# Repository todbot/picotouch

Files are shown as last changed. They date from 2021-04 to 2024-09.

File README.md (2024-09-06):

# picotouch

Tiny capsense touch USB MIDI keyboard from a Raspberry Pi Pico
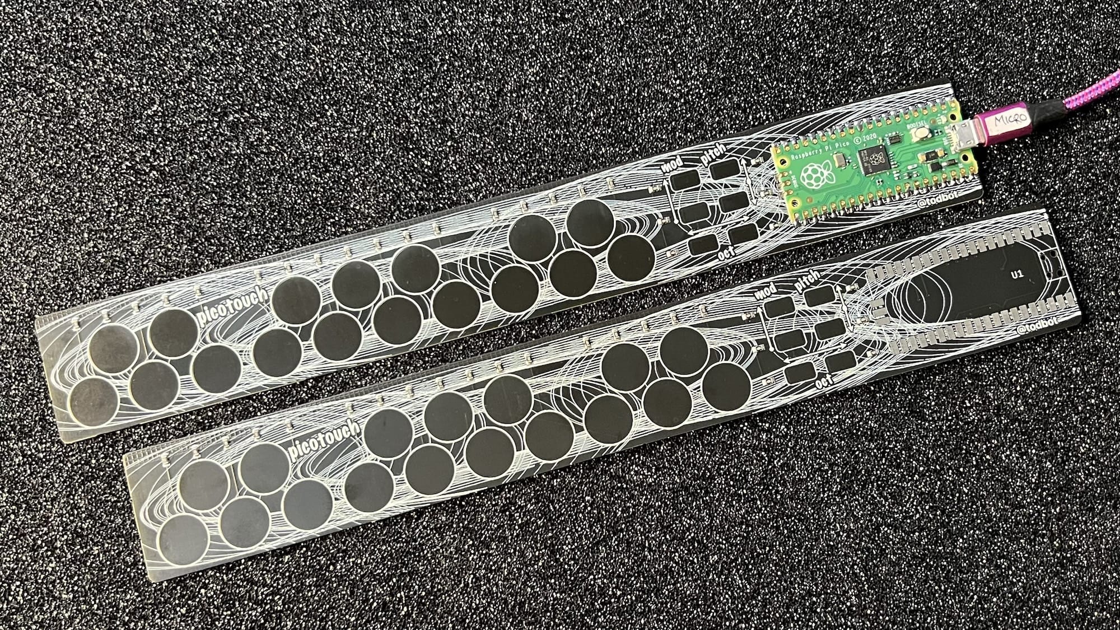
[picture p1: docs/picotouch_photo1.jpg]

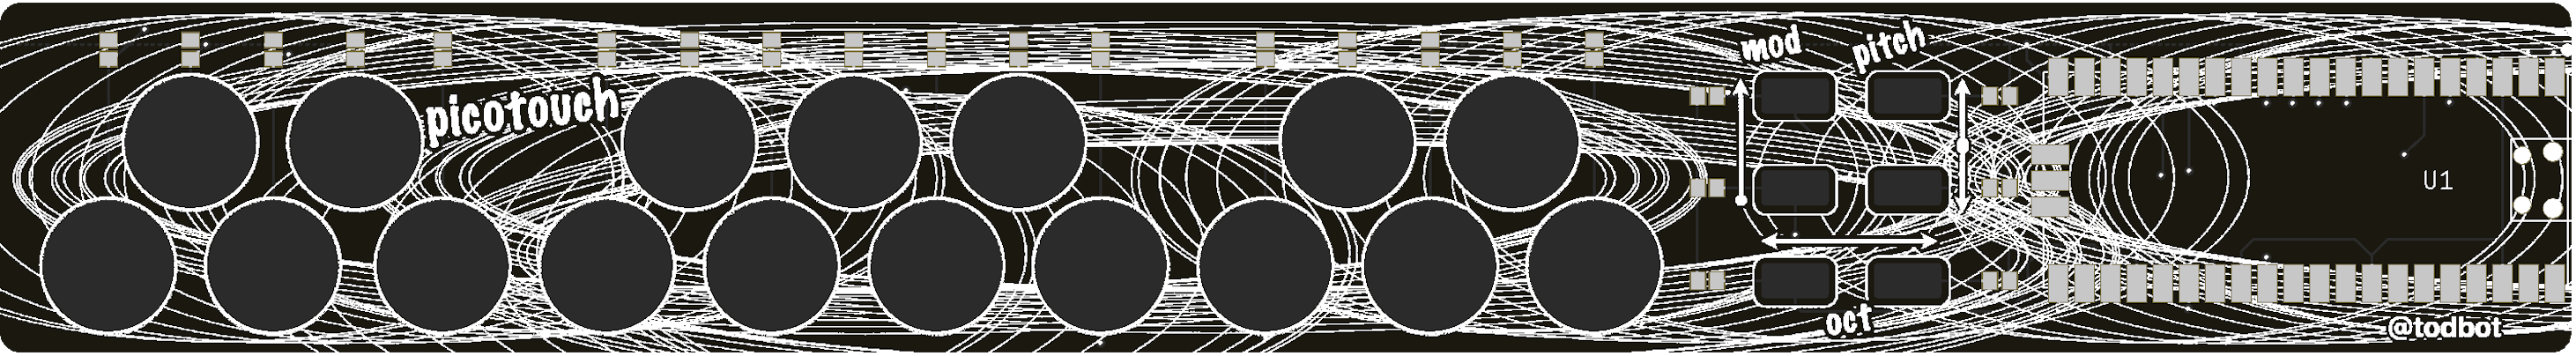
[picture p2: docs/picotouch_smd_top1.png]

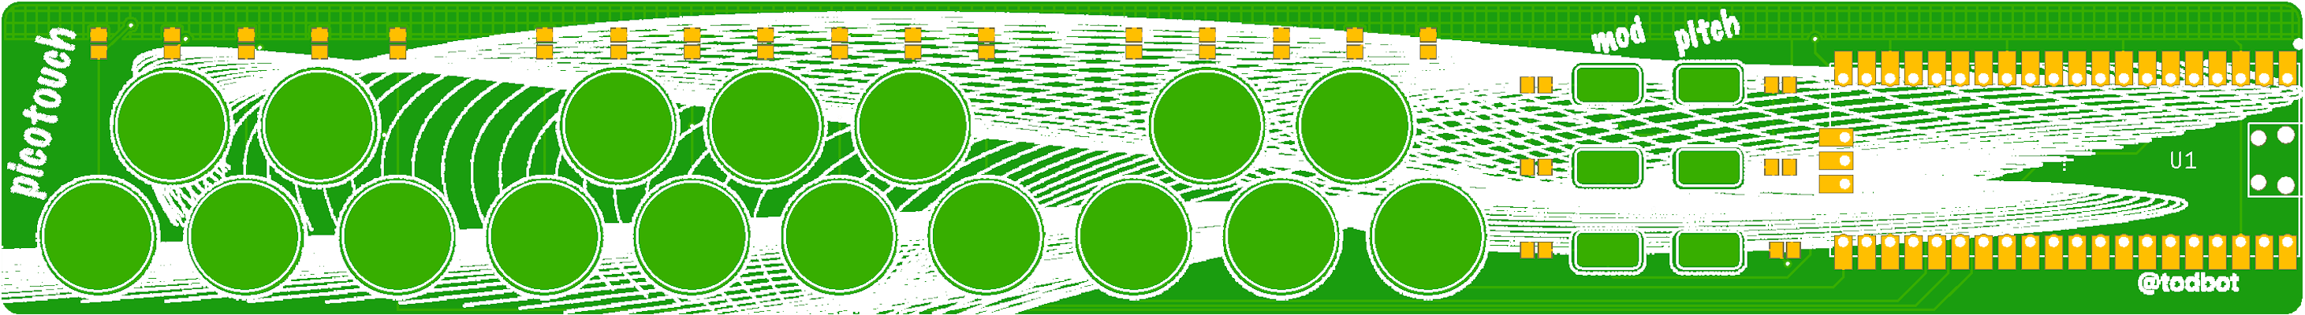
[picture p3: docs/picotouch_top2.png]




If you're looking for the synthesizer version,
that's at [github.com/todbot/picotouch_synth](https://github.com/todbot/picotouch_synth)

## Demos

https://user-images.githubusercontent.com/274093/216477797-90a1e4ca-b68f-4eb2-be46-de1d6d81551e.mp4

Also see videos in this Twitter thread : https://twitter.com/todbot/status/1382469033061093377

And check out [picotouch videos on my Youtube channel](https://www.youtube.com/@todbot/search?query=picotouch)

## Materials needed

If you [buy a black 'picotouch SMD' board from my Tindie store](https://www.tindie.com/products/todbot/picotouch-capsense-midi-keyboard-for-raspi-pico/), the <b>resistors are soldered</b> for you, so you only need to
[solder the Pico](https://www.youtube.com/watch?v=dW9LiOq3Dso).

If you're building one by hand, you will need:
- 1 - picotouch PCB ([order from OSHpark](https://oshpark.com/shared_projects/5MnI1jPf))
- 1 - Raspberry Pi Pico  **(NOTE: Not the Pico2, since its RP2350 chip has a hardware error)**
- 23 - 1M ohm 0805 SMD resistors  ([Digikey cart with this & Pico](https://www.digikey.com/short/w381rn4w))

## How to solder the Pico

It's not too bad!  A pretty easy first-time SMD soldering project.  Here's
[how to solder the Pico down](https://www.youtube.com/watch?v=dW9LiOq3Dso).
The technique is: line up the Pico solder one corner, solder the other, then finish all the rest.
In the video you see I don't get it aligned perfectly straight (hard to see around the camera), but it still works great!  ([Youtube version of the below video](https://www.youtube.com/watch?v=dW9LiOq3Dso))

https://user-images.githubusercontent.com/274093/217670870-b04d55ed-e37d-4be2-bea7-4985d2b3f8c4.mp4

## Firmware Installation

* Install CircuitPython
  - Hold down BOOT button while plugging in Pico to get RPI-RP2 drive
  - Download CircuitPython UF2 from https://circuitpython.org/board/raspberry_pi_pico/
  - Drag UF2 to RPI-RP2 drive. CircuitPython is now installed!

* Install CircuitPython libraries onto Pico
  - If you have Python on your computer you can do:
    ```
    pip3 install circup
    circup install adafruit_midi adafruit_debouncer adafruit_ticks
    ```
  - Otherwise, download the CircuitPython Libraries Bundle at https://circuitpython.org/libraries
    and copy over the `adafruit_midi`, `adafruit_debouncer`, & `adafruit_ticks` libraries
    to the `CIRCUITPY/lib` folder on the Pico.

* Install picotouch `code.py`
  - Via commandline:
    ```
    cp picotouch/circuitpython/picotouch/code.py /Volumes/CIRCUITPY/code.py
    ```
  - Or you can drag-n-drop using your computer's GUI
  - Note: this will delete the previous `code.py` on your Pico.
      Normally this is fine, but if it's not, be sure to save it if you want to keep it!

## Going further

There's other things you can do with the picotouch board.

- Use it as a MIDI slider bank

    Install
   [`picotouch_midislider/code.py`](https://github.com/todbot/picotouch/blob/main/circuitpython/picotouch_midislider/code.py) instead of the regular picotouch code.py.

   - youtube demo: [midislider demo video](https://youtu.be/1Psw3PLqYS8)

- Use it as a HID keyboard macropad

   - example code: [`picotouch_macropad/code.py`](https://github.com/todbot/picotouch/blob/main/circuitpython/picotouch_macropad/code.py)

   It's early days, but it's a start at that idea

## Press

- https://www.hackster.io/news/tod-kurt-s-ultra-slim-picotouch-is-a-button-free-23-key-raspberry-pi-pico-powered-midi-keyboard-700a3ce2227b (26 Feb 2023)
- https://www.raspberrypi.com/news/picotouch-synthesiser-magpimonday/ (22 Nov 2023)

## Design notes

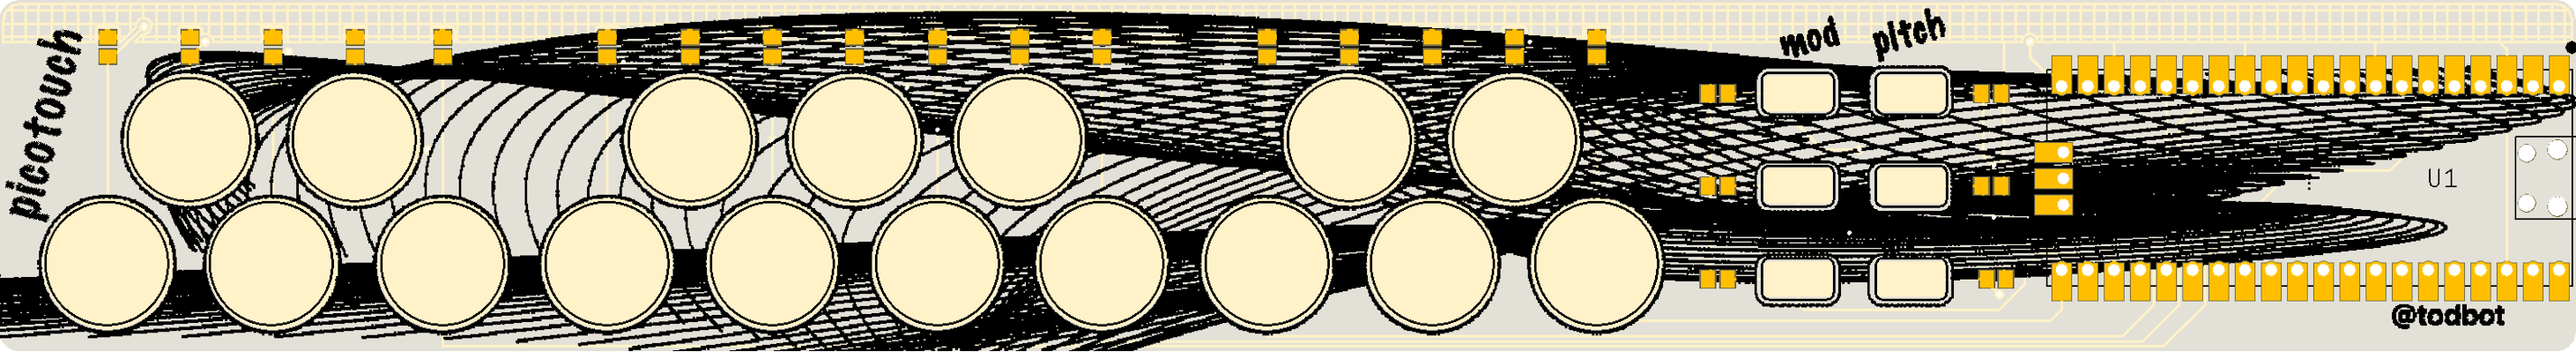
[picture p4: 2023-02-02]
docs/picotouch_top1.png

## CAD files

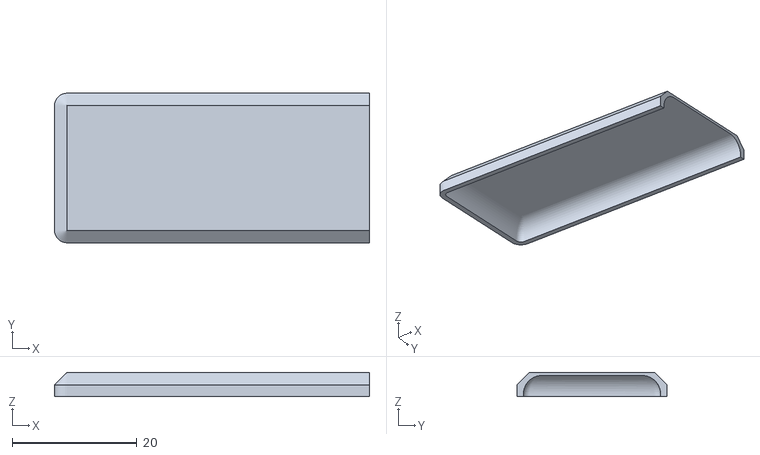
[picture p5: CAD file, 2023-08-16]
enclosure/picotouch_slidercase_picocap.stl
50.5 x 24.0 x 3.90

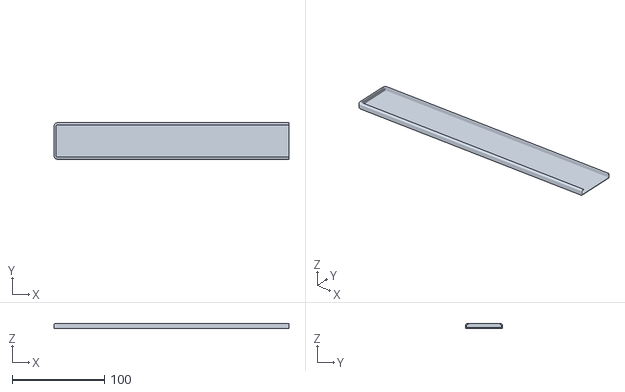
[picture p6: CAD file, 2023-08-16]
enclosure/picotouch_slidercase_bottom.stl
255.0 x 39.8 x 5.30

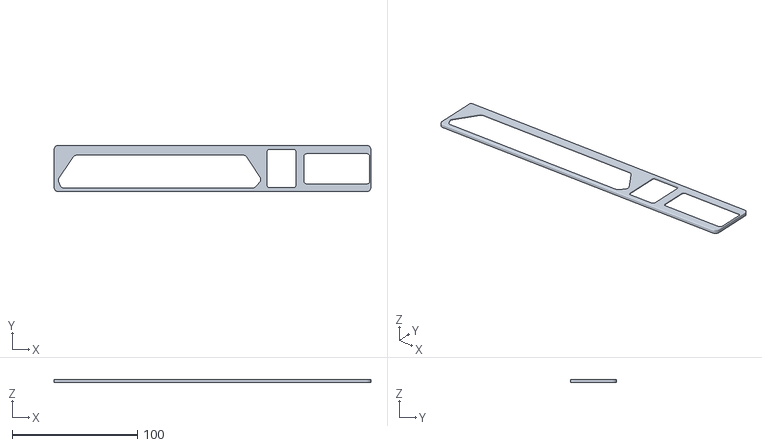
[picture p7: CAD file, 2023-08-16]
enclosure/picotouch_slidercase_top.stl
253.0 x 37.0 x 2.70

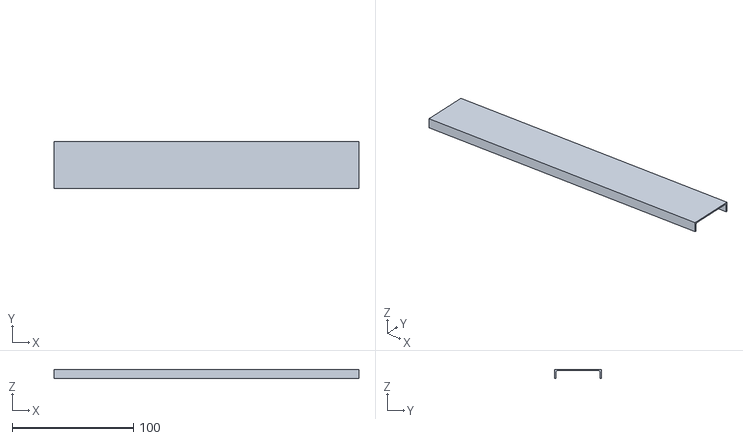
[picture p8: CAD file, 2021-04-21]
enclosure/picotouch_enclosure_top.stl
251.4 x 38.6 x 7.77

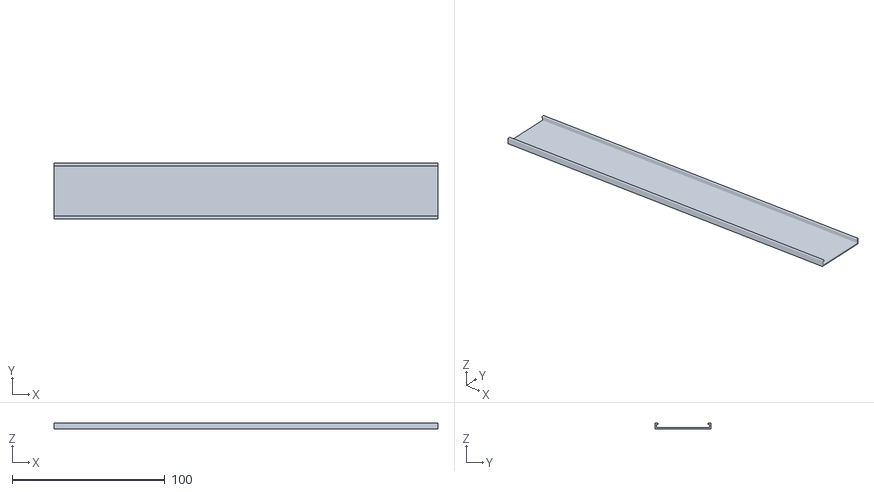
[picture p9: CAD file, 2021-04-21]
enclosure/picotouch_enclosure.stl
251.4 x 36.4 x 3.97

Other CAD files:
enclosure/picotouch_enclosure.f3z
enclosure/picotouch_slidercase v27.f3z

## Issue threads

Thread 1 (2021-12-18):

How the basic reading of individual electrode works

Sciss, 2021-12-18:
Hi there. I'm trying to understand how I could use your project as a starting point for getting capacitive proximity sensing done on a Pi Pico. If I want to bypass the PCB, what would be the minimum setup to connect a single electrode? I am looking at the [touchio API](https://circuitpython.readthedocs.io/en/latest/shared-bindings/touchio/index.html), but I don't understand how this works with a single pin. I suppose this one GPIO pin that gets toggled between output (temporary switching from low to high) and input (then reading, "counting" the delay till it returns to low)? What does your circuit do exactly; it connects one GPIO pin to one electrode, and in parallel with 1 MOhms to GND or something like that? Thanks!

todbot, 2021-12-18:
Hi,
For each `touchio` capacitive touch sensor input, all you need is one 1M ohm to ground. So it's not really a circuit exactly, just some wiring with a resistor.  There's a bit more detail about CircuitPython cap touch here: https://learn.adafruit.com/circuitpython-essentials/circuitpython-cap-touch

This video post on Twitter shows the same circuit as `pictouch` but implemented on a solderless breadboard with just a bunch of resistors, one per input.

To do a single input, it would look something like:
```py
import time
import board
import touchio

# put 1M resistor from GPO to ground, then touch GP0 to trigger
touch = touchio.TouchIn( board.GP0 )

while True:
    if touch.value:
        print("Touched!")
    time.sleep(0.05)
```

To do proximity sensing (as opposed to touch sensing) with capacitive touch, just use more metal connected to your touch input (`board.GP0` in the above example). This "more metal" could be a longer wire, wrapped into a coil, a metal plate, etc.  Note that proximity sensing is generally very finicky as it will vary based on person, ambient humidity, battery voltage, and other environmental factors.

But here's an example of doing proximity capacitive sensing using CircuitPython:
https://github.com/todbot/qtpy-tricks#use-capsense-as-proximity-detector-to-make-spooopy-ghost

Sciss, 2021-12-19:
Thanks a lot for taking the time, I'll try this out. It's all a bit of a mystery, there is just a confusing amount of alternative touch sensing designs out there :)

todbot, 2021-12-19:
Yes, it can be confusing.  Fundamentally they are all working the same way, just as you outlined: a GPIO pin is switched to an output, set HIGH to charge the pin capacitance, then switched to input and time how long it takes to go LOW through a known resistance.

In some chips, this functionality is implemented in hardware, with an internal resistor and timing circuitry. In other implementations, the sense resistor is connected to two pins so it can be charged in both directions (which can improve results). And every chip vendor has their own version of an API on how to do it.

CircuitPython attempts to simplify things by providing one `touchio` API that attempts to hide all that variation, even though there's about four or so different vendor APIs, depending on which chip is running CircuitPython.

Closed 2021-12-19.

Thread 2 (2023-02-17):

Stuck MIDI notes when changing octaves

Naenyn, 2023-02-17:
If a note is played and held while the octave buttons are used, the note becomes "stuck" on until the user switches back to that octave and touches that same note again.

Personally I'd prefer switching octaves to send a note-off, but I'm sure there are other ways it could be handled (including not changing it at all).

todbot, 2023-02-18:
Yeah it's a problem.  Looking at it now.

Closed 2023-02-18.

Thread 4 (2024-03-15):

CircuitPython over Arduino

llgcode, 2024-03-15:
Hi,
really interesting project.

I work on a footswitch controller with a remote board with buttons and led that fit my "musician" workflow on bitwig.
I like your use of capacitive button, how to you make it ?

I've seen that you've tried a program with arduino framework, why did you choose circuitPython over arduino ?
Is better or easier to dev ?

todbot, 2024-03-15:
Hi!
Yes, in general doing initial development is much faster in CircuitPython than Arduino. Since you're editing a text file directly on the board and saving that file causes it to be run means the iteration cycle can be much faster than reprogramming the board.  There is also many modern useful libraries either built directly into CircuitPython or easily available via the Adafruit and Community Library Bundles.

The capacitive buttons are just small areas of copper on the PCB. This is really how all capacitive buttons work. The cleverness is in the firmware on the board. (CircuitPython has a `touchio` library to help with this)

You can mock up capacitive buttons using copper tape cut into the shapes you want. (This is what I do when I'm trying out a new idea).  The sizes of these copper pads shouldn't be too big (i.e. no more approximately 50mm x 50mm), since larger pads take longer to read.

llgcode, 2024-03-16:
Thanks for the tape tips, it gives me some idea of a prototype board where I could stick some tape on a piece of wood and some wires connected to it ^^.

For python code I understand that it's easier to dev. So the CPP code that you developed work as expected.

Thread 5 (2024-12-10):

Pull down

wadebob, 2024-12-10:
Such a neat project. I'm an electronics noob so probably a very simple reason for this but curious as to why you used smd resistors instead of using the built in pull down functionality on the pico?

todbot, 2024-12-10:
The built-in pull-downs are in the range of 10k-20k.  The external pull-down resistors are 1M.  The higher resistance is needed to be able to measure the small capacitance of the touch pad and how it changes when you touch it.  This is done by measuring the time it takes for the pin to go LOW after being set HIGH. That time is on the order of microseconds with a 1M resistor. With a 10k resistor it would be in the nanosecond range: too fast to measure

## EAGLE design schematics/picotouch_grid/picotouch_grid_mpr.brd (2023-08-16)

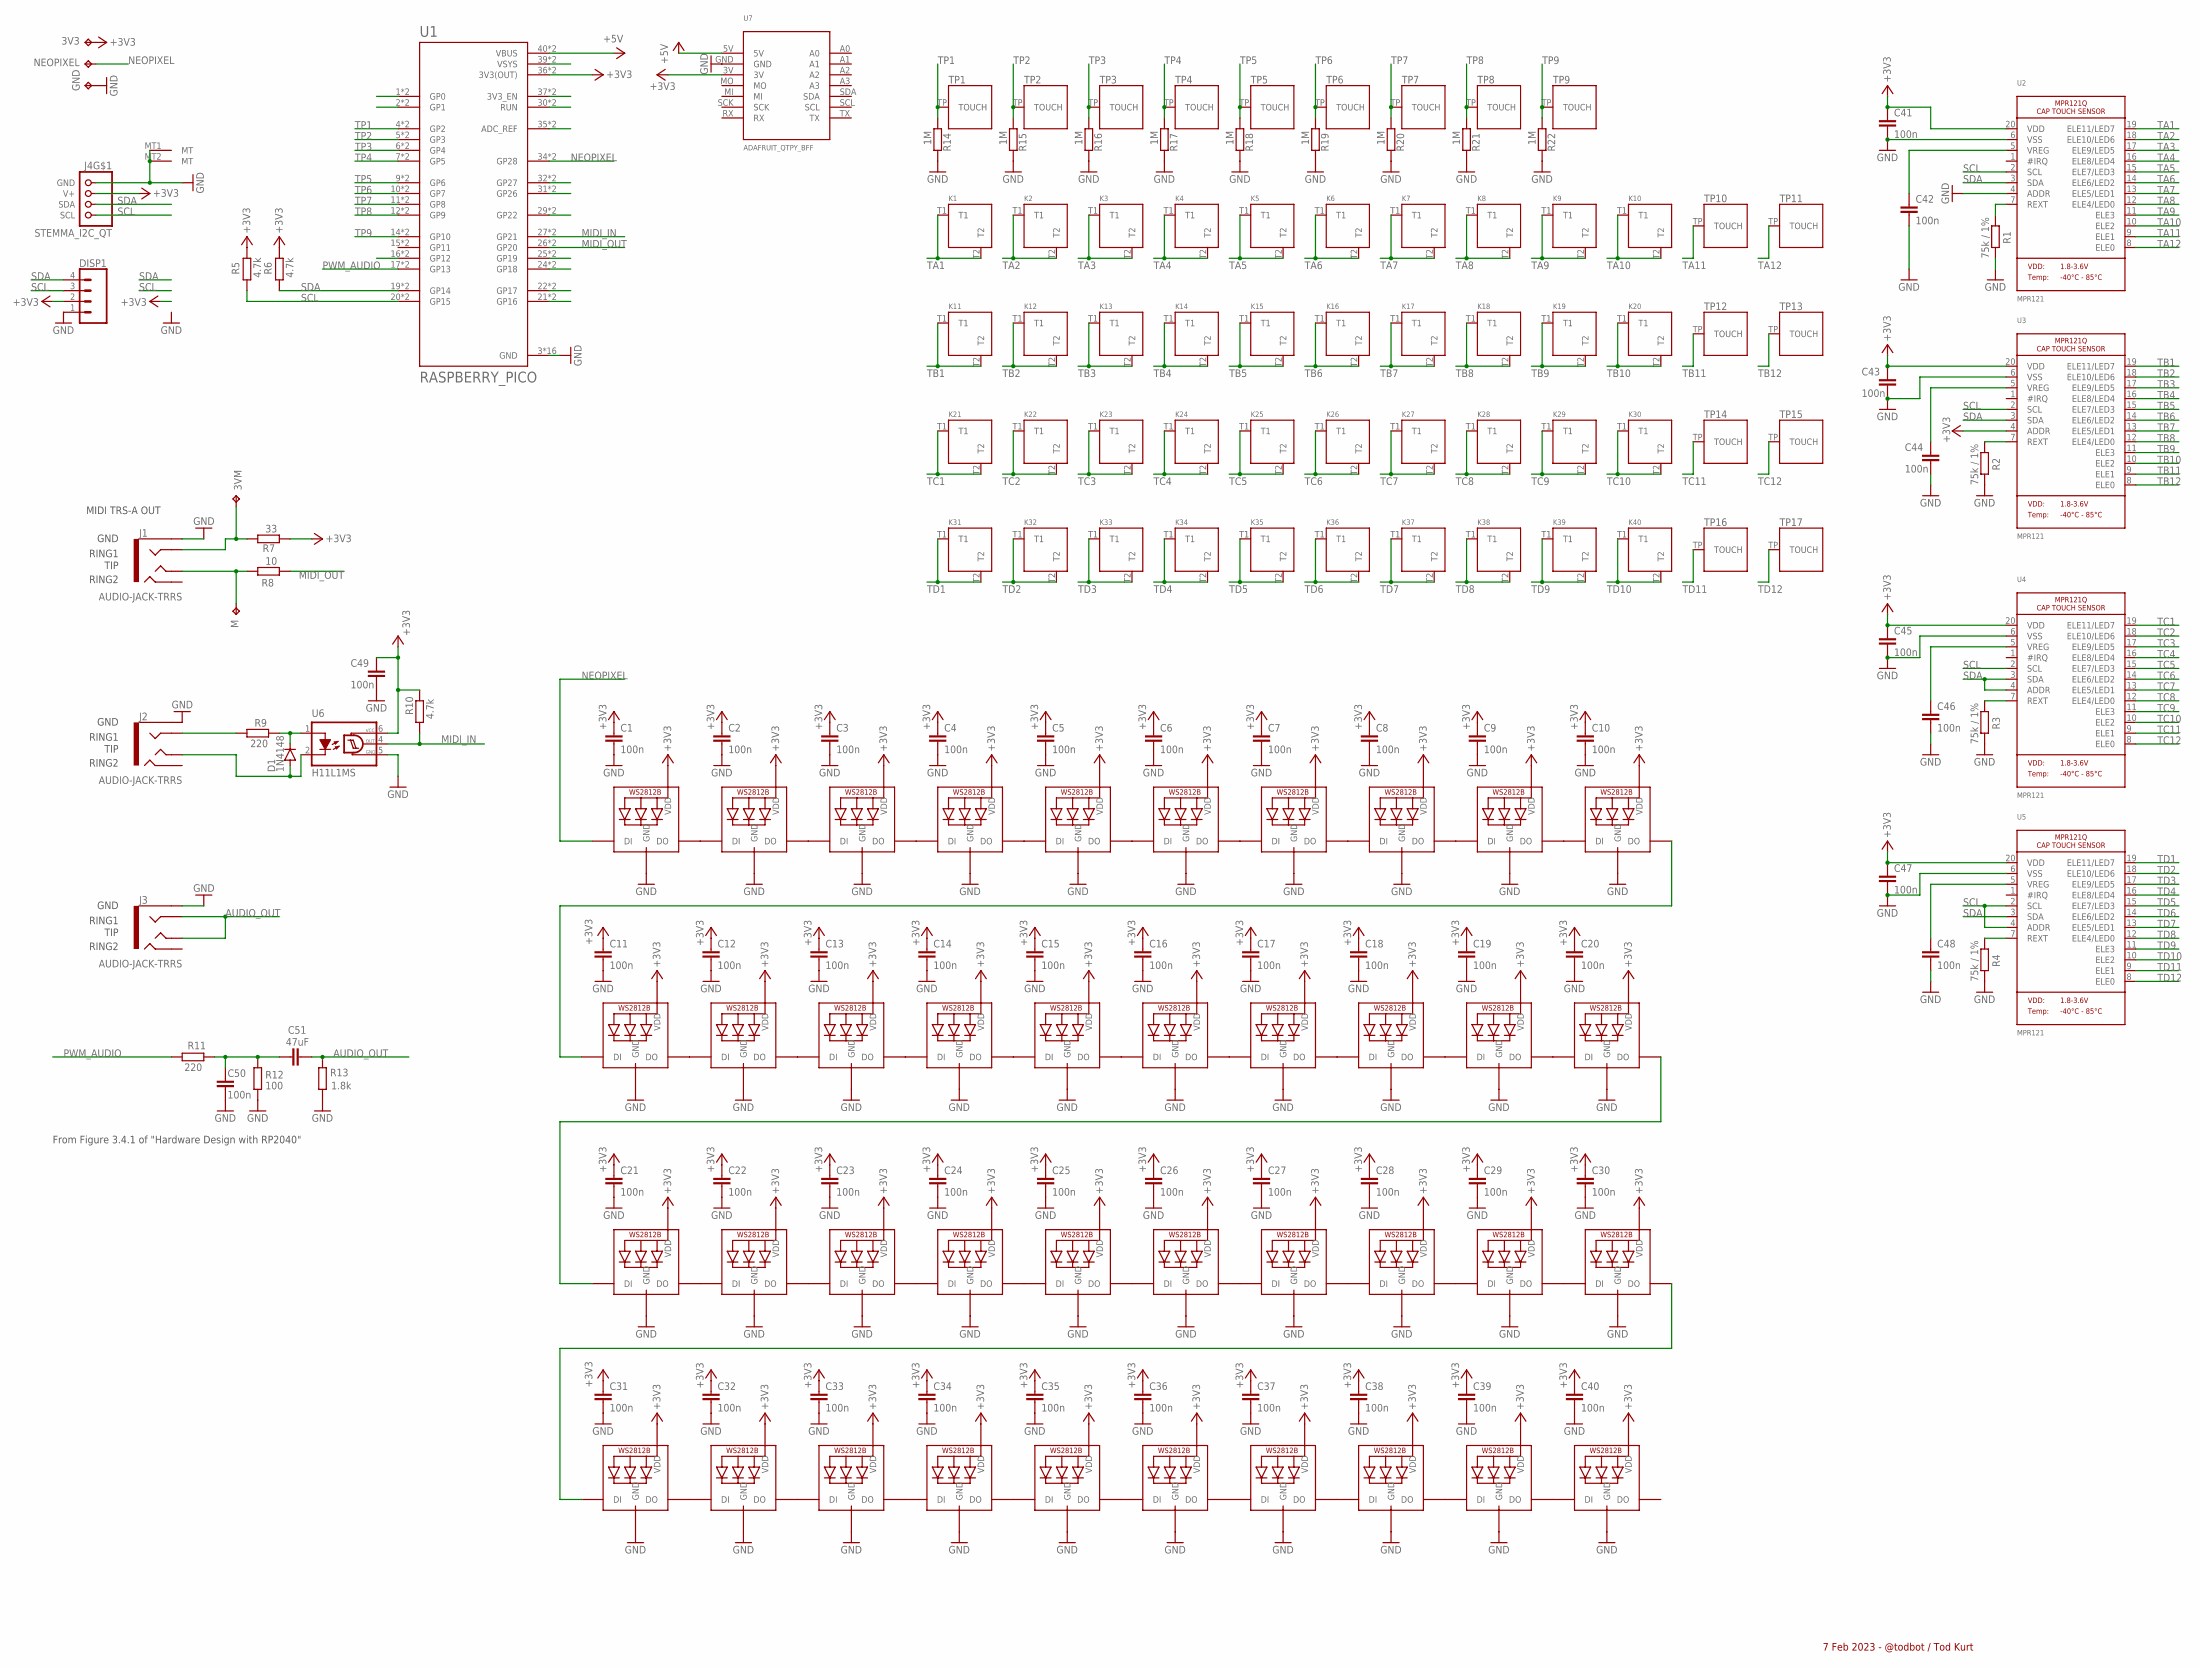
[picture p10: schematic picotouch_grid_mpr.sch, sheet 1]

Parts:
3V3, 3VM: TPTP15R; TP15R
C1, C2, C3, C4, C5, C6, C7, C8, C9, C10, C11, C12, C13, C14, C15, C16, C17, C18, C19, C20, C21, C22, C23, C24, C25, C26, C27, C28, C29, C30, C31, C32, C33, C34, C35, C36, C37, C38, C39, C40, C41, C42, C43, C44, C45, C46, C47, C48, C49, C50: 100n; C0603
C51: 47uF; C0805
D1: 1N4148; SOD123
DISP1: CONN_04; 1X04
GND: TPTP15R; TP15R
J1, J3: AUDIO-JACK-TRRS; PJ-320D_SPARKFUN; LCSC C431535
J2: AUDIO-JACK-TRRS; PJ-320D_SPARKFUN
J4: STEMMA_I2C_QT; JST_SH4; MPN HC-1.0-4PWT; LCSC2 C160404
K1, K2, K3, K4, K5, K6, K7, K8, K9, K10, K11, K12, K13, K14, K15, K16, K17, K18, K19, K20, K21, K22, K23, K24, K25, K26, K27, K28, K29, K30, K31, K32, K33, K34, K35, K36, K37, K38, K39, K40: TOUCHKEYH; TOUCHPAD_KEY_0.5IN_LEDHOLE
LED1: MICROBUILDER_WS2812B_SK6812E; MICROBUILDER_NEO3535_REVERSE; LCSC C5149201
LED2, LED3, LED4, LED5, LED6, LED7, LED8, LED9, LED10, LED11, LED12, LED13, LED14, LED15, LED16, LED17, LED18, LED19, LED20, LED21, LED22, LED23, LED24, LED25, LED26, LED27, LED28, LED29, LED30, LED31, LED32, LED33, LED34, LED35, LED36, LED37, LED38, LED39, LED40: MICROBUILDER_WS2812B_SK6812E; MICROBUILDER_NEO3535_REVERSE
M: TPTP15R; TP15R
NEOPIXEL: TPTP15R; TP15R
R1, R2, R3, R4: 75k / 1%; R0603
R5, R6, R10: 4.7k; R0603
R7: 33; R0603
R8: 10; R0603
R9, R11: 220; R0603
R12: 100; R0603
R13: 1.8k; R0603
R14, R15, R16, R17, R18, R19, R20, R21, R22: 1M; R0603
TP1, TP2, TP3, TP4, TP5, TP6, TP7, TP8, TP9, TP10, TP11, TP12, TP13, TP14, TP15, TP16, TP17: TOUCHPADB
U1: RASPBERRY_PICO; PICO-PKG-DUALSMD
U2, U3, U4, U5: MPR121; QFN20_3MM_NOTHERMAL; LCSC C91322
U6: H11L1MS; DIL6-SMD; MPN2 H11L1S; LCSC C78589
U7: ADAFRUIT_QTPY_BFF; ADAFRUIT_QTPY_BFF_LIPO

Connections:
+3V3: 3V3.TP, C1.1, C2.1, C3.1, C4.1, C5.1, C6.1, C7.1, C8.1, C9.1, C10.1, C11.1, C12.1, C13.1, C14.1, C15.1, C16.1, C17.1, C18.1, C19.1, C20.1, C21.1, C22.1, C23.1, C24.1, C25.1, C26.1, C27.1, C28.1, C29.1, C30.1, C31.1, C32.1, C33.1, C34.1, C35.1, C36.1, C37.1, C38.1, C39.1, C40.1, C41.1, C43.1, C45.1, C47.1, C49.1, DISP1.2, J4.2 (V+), LED1.1-VDD (VDD), LED2.1-VDD (VDD), LED3.1-VDD (VDD), LED4.1-VDD (VDD), LED5.1-VDD (VDD), LED6.1-VDD (VDD), LED7.1-VDD (VDD), LED8.1-VDD (VDD), LED9.1-VDD (VDD), LED10.1-VDD (VDD), LED11.1-VDD (VDD), LED12.1-VDD (VDD), LED13.1-VDD (VDD), LED14.1-VDD (VDD), LED15.1-VDD (VDD), LED16.1-VDD (VDD), LED17.1-VDD (VDD), LED18.1-VDD (VDD), LED19.1-VDD (VDD), LED20.1-VDD (VDD), LED21.1-VDD (VDD), LED22.1-VDD (VDD), LED23.1-VDD (VDD), LED24.1-VDD (VDD), LED25.1-VDD (VDD), LED26.1-VDD (VDD), LED27.1-VDD (VDD), LED28.1-VDD (VDD), LED29.1-VDD (VDD), LED30.1-VDD (VDD), LED31.1-VDD (VDD), LED32.1-VDD (VDD), LED33.1-VDD (VDD), LED34.1-VDD (VDD), LED35.1-VDD (VDD), LED36.1-VDD (VDD), LED37.1-VDD (VDD), LED38.1-VDD (VDD), LED39.1-VDD (VDD), LED40.1-VDD (VDD), R5.1, R6.1, R7.2, R10.1, U1.36 (3V3(OUT)), U1.36' (3V3(OUT)), U2.20 (VDD), U3.4 (ADDR), U3.20 (VDD), U4.20 (VDD), U5.20 (VDD), U6.6 (VCC), U7.3V
+5V: U1.40 (VBUS), U1.40' (VBUS), U7.5V
AUDIO_OUT: C51.2, J3.RING1, J3.TIP, R13.1
GND: C1.2, C2.2, C3.2, C4.2, C5.2, C6.2, C7.2, C8.2, C9.2, C10.2, C11.2, C12.2, C13.2, C14.2, C15.2, C16.2, C17.2, C18.2, C19.2, C20.2, C21.2, C22.2, C23.2, C24.2, C25.2, C26.2, C27.2, C28.2, C29.2, C30.2, C31.2, C32.2, C33.2, C34.2, C35.2, C36.2, C37.2, C38.2, C39.2, C40.2, C41.2, C42.2, C43.2, C44.2, C45.2, C46.2, C47.2, C48.2, C49.2, C50.2, DISP1.1, GND.TP, J1.EARTH, J2.EARTH, J3.EARTH, J4.1 (GND), J4.MT1 (MT), J4.MT2 (MT), LED1.3-GND (GND), LED2.3-GND (GND), LED3.3-GND (GND), LED4.3-GND (GND), LED5.3-GND (GND), LED6.3-GND (GND), LED7.3-GND (GND), LED8.3-GND (GND), LED9.3-GND (GND), LED10.3-GND (GND), LED11.3-GND (GND), LED12.3-GND (GND), LED13.3-GND (GND), LED14.3-GND (GND), LED15.3-GND (GND), LED16.3-GND (GND), LED17.3-GND (GND), LED18.3-GND (GND), LED19.3-GND (GND), LED20.3-GND (GND), LED21.3-GND (GND), LED22.3-GND (GND), LED23.3-GND (GND), LED24.3-GND (GND), LED25.3-GND (GND), LED26.3-GND (GND), LED27.3-GND (GND), LED28.3-GND (GND), LED29.3-GND (GND), LED30.3-GND (GND), LED31.3-GND (GND), LED32.3-GND (GND), LED33.3-GND (GND), LED34.3-GND (GND), LED35.3-GND (GND), LED36.3-GND (GND), LED37.3-GND (GND), LED38.3-GND (GND), LED39.3-GND (GND), LED40.3-GND (GND), R1.1, R2.1, R3.1, R4.1, R12.1, R13.2, R14.1, R15.1, R16.1, R17.1, R18.1, R19.1, R20.1, R21.1, R22.1, U1.3 (GND), U1.3' (GND), U1.8 (GND), U1.8' (GND), U1.13 (GND), U1.13' (GND), U1.18 (GND), U1.18' (GND), U1.23 (GND), U1.23' (GND), U1.28 (GND), U1.28' (GND), U1.33 (GND), U1.33' (GND), U1.38 (GND), U1.38' (GND), U2.4 (ADDR), U2.6 (VSS), U3.6 (VSS), U4.6 (VSS), U5.6 (VSS), U6.5 (GND), U7.GND
MIDI_IN: R10.2, U1.27 (GP21), U1.27' (GP21), U6.4 (OUT)
MIDI_OUT: R8.2, U1.26 (GP20), U1.26' (GP20)
unnamed: LED1.2-DOUT (DO), LED2.4-DIN (DI)
unnamed: LED2.2-DOUT (DO), LED3.4-DIN (DI)
unnamed: LED4.2-DOUT (DO), LED5.4-DIN (DI)
unnamed: LED5.2-DOUT (DO), LED6.4-DIN (DI)
unnamed: LED3.2-DOUT (DO), LED4.4-DIN (DI)
unnamed: LED7.2-DOUT (DO), LED8.4-DIN (DI)
unnamed: LED8.2-DOUT (DO), LED9.4-DIN (DI)
unnamed: J1.TIP, M.TP, R8.1
unnamed: LED11.2-DOUT (DO), LED12.4-DIN (DI)
unnamed: LED9.2-DOUT (DO), LED10.4-DIN (DI)
unnamed: LED6.2-DOUT (DO), LED7.4-DIN (DI)
unnamed: LED14.2-DOUT (DO), LED15.4-DIN (DI)
unnamed: LED15.2-DOUT (DO), LED16.4-DIN (DI)
unnamed: LED13.2-DOUT (DO), LED14.4-DIN (DI)
unnamed: LED17.2-DOUT (DO), LED18.4-DIN (DI)
unnamed: LED18.2-DOUT (DO), LED19.4-DIN (DI)
unnamed: LED19.2-DOUT (DO), LED20.4-DIN (DI)
unnamed: LED16.2-DOUT (DO), LED17.4-DIN (DI)
unnamed: LED12.2-DOUT (DO), LED13.4-DIN (DI)
unnamed: LED21.2-DOUT (DO), LED22.4-DIN (DI)
unnamed: LED22.2-DOUT (DO), LED23.4-DIN (DI)
unnamed: LED24.2-DOUT (DO), LED25.4-DIN (DI)
unnamed: LED25.2-DOUT (DO), LED26.4-DIN (DI)
unnamed: LED23.2-DOUT (DO), LED24.4-DIN (DI)
unnamed: LED27.2-DOUT (DO), LED28.4-DIN (DI)
unnamed: LED28.2-DOUT (DO), LED29.4-DIN (DI)
unnamed: LED31.2-DOUT (DO), LED32.4-DIN (DI)
unnamed: LED29.2-DOUT (DO), LED30.4-DIN (DI)
unnamed: LED26.2-DOUT (DO), LED27.4-DIN (DI)
unnamed: LED34.2-DOUT (DO), LED35.4-DIN (DI)
unnamed: LED35.2-DOUT (DO), LED36.4-DIN (DI)
unnamed: LED33.2-DOUT (DO), LED34.4-DIN (DI)
unnamed: LED37.2-DOUT (DO), LED38.4-DIN (DI)
unnamed: LED38.2-DOUT (DO), LED39.4-DIN (DI)
unnamed: LED39.2-DOUT (DO), LED40.4-DIN (DI)
unnamed: LED36.2-DOUT (DO), LED37.4-DIN (DI)
unnamed: LED32.2-DOUT (DO), LED33.4-DIN (DI)
unnamed: 3VM.TP, J1.RING1, R7.1
unnamed: U1.21 (GP16), U1.21' (GP16)
unnamed: U1.22 (GP17), U1.22' (GP17)
unnamed: U1.24 (GP18), U1.24' (GP18)
unnamed: U1.25 (GP19), U1.25' (GP19)
unnamed: R2.2, U3.7 (REXT)
unnamed: C44.1, U3.5 (VREG)
unnamed: U1.32 (GP27), U1.32' (GP27)
unnamed: D1.C, R9.1, U6.1 (A)
unnamed: D1.A, J2.TIP, U6.2 (C)
unnamed: J2.RING1, R9.2
unnamed: R4.2, U5.7 (REXT)
unnamed: C48.1, U5.5 (VREG)
unnamed: U1.31 (GP26), U1.31' (GP26)
unnamed: U1.29 (GP22), U1.29' (GP22)
unnamed: U1.35 (ADC_REF), U1.35' (ADC_REF)
unnamed: U1.30 (RUN), U1.30' (RUN)
unnamed: C50.1, C51.1, R11.1, R12.2
unnamed: U1.37 (3V3_EN), U1.37' (3V3_EN)
unnamed: U1.2 (GP1), U1.2' (GP1)
unnamed: R3.2, U4.7 (REXT)
unnamed: C46.1, U4.5 (VREG)
unnamed: U1.1 (GP0), U1.1' (GP0)
unnamed: U1.39 (VSYS), U1.39' (VSYS)
unnamed: U1.16 (GP12), U1.16' (GP12)
unnamed: C42.1, U2.5 (VREG)
unnamed: R1.2, U2.7 (REXT)
NEOPIXEL: LED1.4-DIN (DI), NEOPIXEL.TP, U1.34 (GP28), U1.34' (GP28)
NEOPIXEL0: LED10.2-DOUT (DO), LED11.4-DIN (DI)
NEOPIXEL1: LED20.2-DOUT (DO), LED21.4-DIN (DI)
NEOPIXEL2: LED30.2-DOUT (DO), LED31.4-DIN (DI)
PWM_AUDIO: R11.2, U1.17 (GP13), U1.17' (GP13)
SCL: DISP1.3, J4.4 (SCL), R5.2, U1.20 (GP15), U1.20' (GP15), U2.2 (SCL), U3.2 (SCL), U4.2 (SCL), U5.2 (SCL), U5.4 (ADDR)
SDA: DISP1.4, J4.3 (SDA), R6.2, U1.19 (GP14), U1.19' (GP14), U2.3 (SDA), U3.3 (SDA), U4.3 (SDA), U4.4 (ADDR), U5.3 (SDA)
TA1: K1.T1, K1.T2, U2.19 (ELE11/LED7)
TA2: K2.T1, K2.T2, U2.18 (ELE10/LED6)
TA3: K3.T1, K3.T2, U2.17 (ELE9/LED5)
TA4: K4.T1, K4.T2, U2.16 (ELE8/LED4)
TA5: K5.T1, K5.T2, U2.15 (ELE7/LED3)
TA6: K6.T1, K6.T2, U2.14 (ELE6/LED2)
TA7: K7.T1, K7.T2, U2.13 (ELE5/LED1)
TA8: K8.T1, K8.T2, U2.12 (ELE4/LED0)
TA9: K9.T1, K9.T2, U2.11 (ELE3)
TA10: K10.T1, K10.T2, U2.10 (ELE2)
TA11: TP10.TP, U2.9 (ELE1)
TA12: TP11.TP, U2.8 (ELE0)
TB1: K11.T1, K11.T2, U3.19 (ELE11/LED7)
TB2: K12.T1, K12.T2, U3.18 (ELE10/LED6)
TB3: K13.T1, K13.T2, U3.17 (ELE9/LED5)
TB4: K14.T1, K14.T2, U3.16 (ELE8/LED4)
TB5: K15.T1, K15.T2, U3.15 (ELE7/LED3)
TB6: K16.T1, K16.T2, U3.14 (ELE6/LED2)
TB7: K17.T1, K17.T2, U3.13 (ELE5/LED1)
TB8: K18.T1, K18.T2, U3.12 (ELE4/LED0)
TB9: K19.T1, K19.T2, U3.11 (ELE3)
TB10: K20.T1, K20.T2, U3.10 (ELE2)
TB11: TP12.TP, U3.9 (ELE1)
TB12: TP13.TP, U3.8 (ELE0)
TC1: K21.T1, K21.T2, U4.19 (ELE11/LED7)
TC2: K22.T1, K22.T2, U4.18 (ELE10/LED6)
TC3: K23.T1, K23.T2, U4.17 (ELE9/LED5)
TC4: K24.T1, K24.T2, U4.16 (ELE8/LED4)
TC5: K25.T1, K25.T2, U4.15 (ELE7/LED3)
TC6: K26.T1, K26.T2, U4.14 (ELE6/LED2)
TC7: K27.T1, K27.T2, U4.13 (ELE5/LED1)
TC8: K28.T1, K28.T2, U4.12 (ELE4/LED0)
TC9: K29.T1, K29.T2, U4.11 (ELE3)
TC10: K30.T1, K30.T2, U4.10 (ELE2)
TC11: TP14.TP, U4.9 (ELE1)
TC12: TP15.TP, U4.8 (ELE0)
TD1: K31.T1, K31.T2, U5.19 (ELE11/LED7)
TD2: K32.T1, K32.T2, U5.18 (ELE10/LED6)
TD3: K33.T1, K33.T2, U5.17 (ELE9/LED5)
TD4: K34.T1, K34.T2, U5.16 (ELE8/LED4)
TD5: K35.T1, K35.T2, U5.15 (ELE7/LED3)
TD6: K36.T1, K36.T2, U5.14 (ELE6/LED2)
TD7: K37.T1, K37.T2, U5.13 (ELE5/LED1)
TD8: K38.T1, K38.T2, U5.12 (ELE4/LED0)
TD9: K39.T1, K39.T2, U5.11 (ELE3)
TD10: K40.T1, K40.T2, U5.10 (ELE2)
TD11: TP16.TP, U5.9 (ELE1)
TD12: TP17.TP, U5.8 (ELE0)
TP1: R14.2, TP1.TP, U1.4 (GP2), U1.4' (GP2)
TP2: R15.2, TP2.TP, U1.5 (GP3), U1.5' (GP3)
TP3: R16.2, TP3.TP, U1.6 (GP4), U1.6' (GP4)
TP4: R17.2, TP4.TP, U1.7 (GP5), U1.7' (GP5)
TP5: R18.2, TP5.TP, U1.9 (GP6), U1.9' (GP6)
TP6: R19.2, TP6.TP, U1.10 (GP7), U1.10' (GP7)
TP7: R20.2, TP7.TP, U1.11 (GP8), U1.11' (GP8)
TP8: R21.2, TP8.TP, U1.12 (GP9), U1.12' (GP9)
TP9: R22.2, TP9.TP, U1.14 (GP10), U1.14' (GP10)

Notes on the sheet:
MIDI TRS-A OUT
RING2
RING1
GND
TIP
7 Feb 2023 - @todbot / Tod Kurt
From Figure 3.4.1 of "Hardware Design with RP2040"

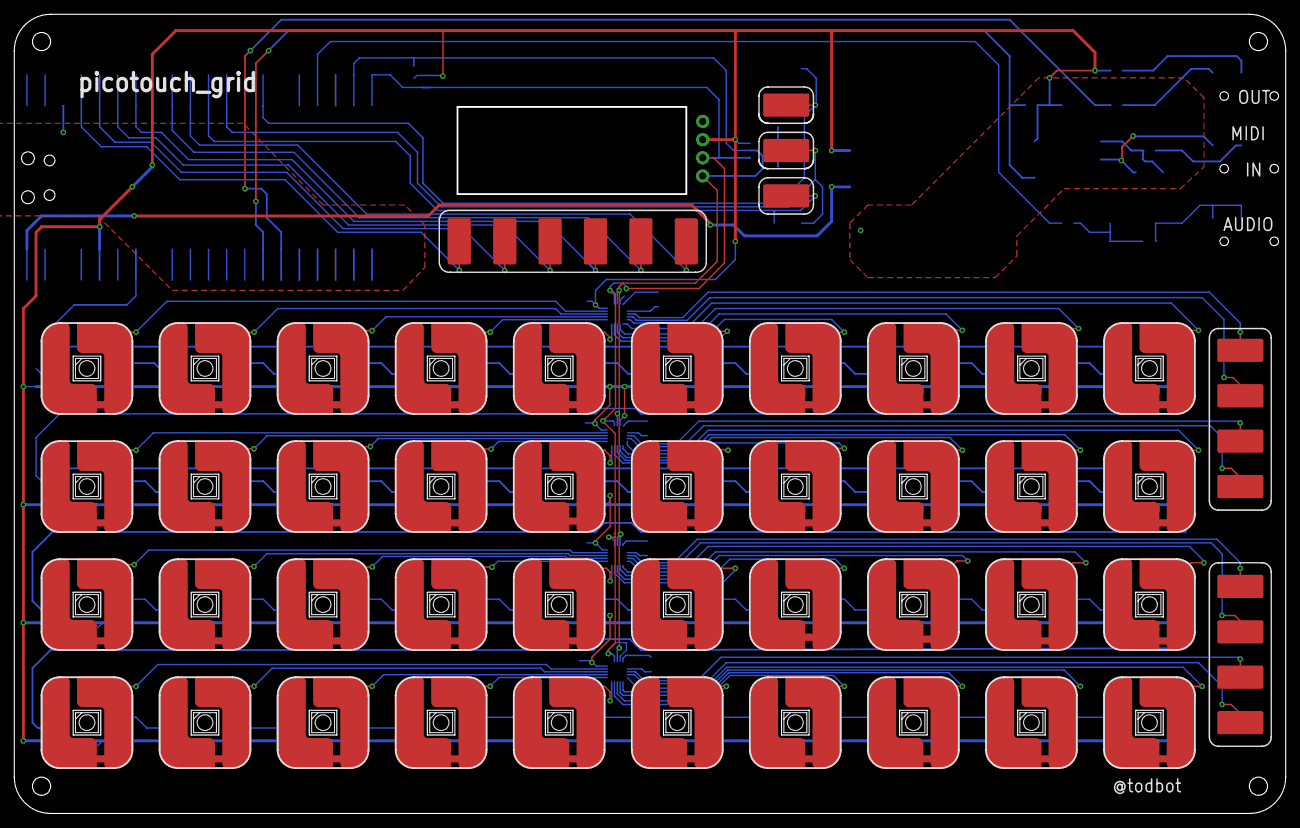
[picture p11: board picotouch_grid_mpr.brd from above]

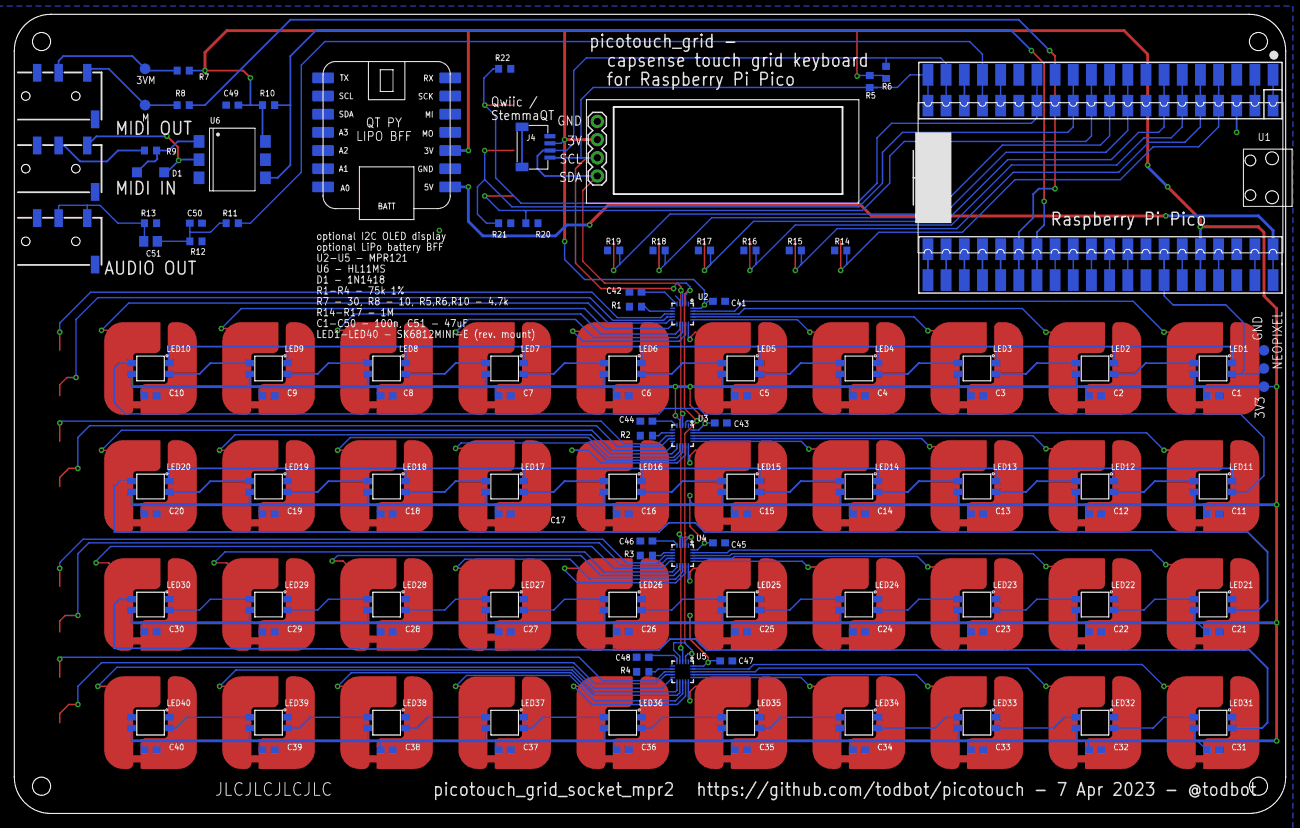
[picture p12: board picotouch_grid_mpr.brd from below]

Board: 2 copper layers, 177.8 x 111.8 mm, 188 parts (91 on the bottom side), 134 nets.

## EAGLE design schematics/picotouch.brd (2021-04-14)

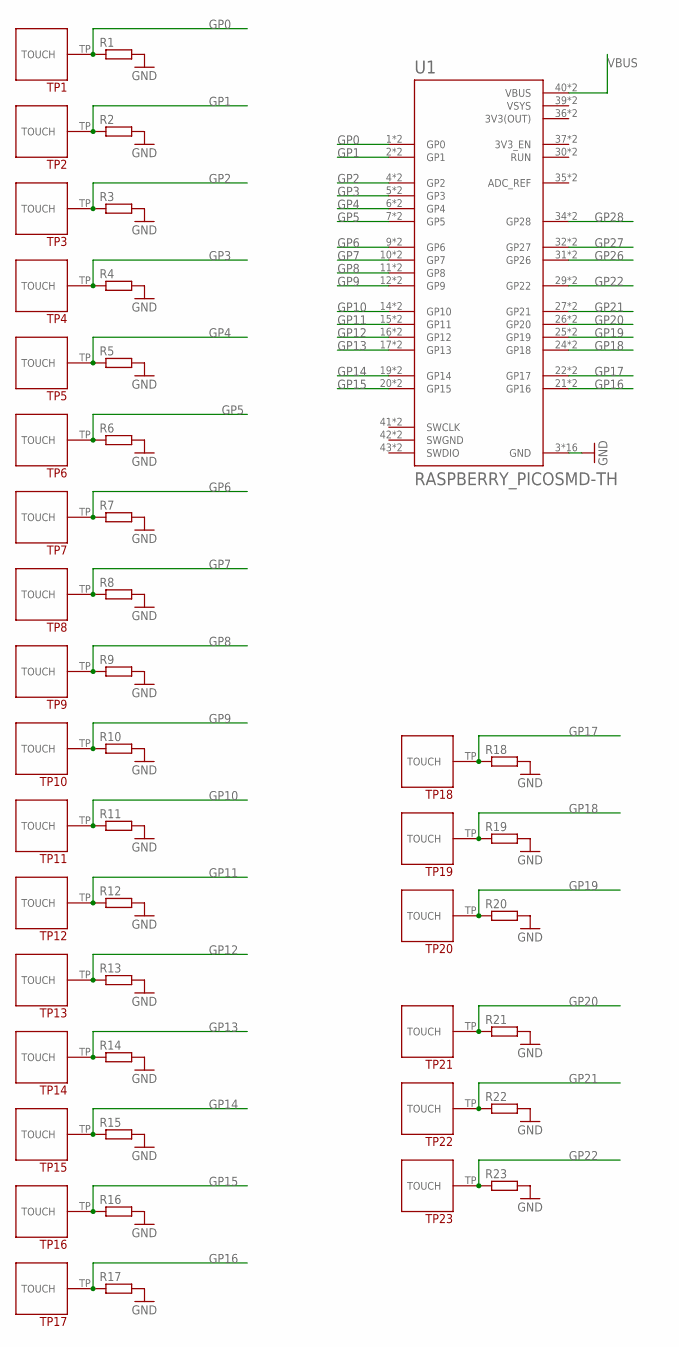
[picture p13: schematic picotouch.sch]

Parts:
R1, R2, R3, R4, R5, R6, R7, R8, R9, R10, R11, R12, R13, R14, R15, R16, R17, R18, R19, R20, R21, R22, R23: R-EU_R0805; R0805
TP1, TP2, TP3, TP4, TP5, TP6, TP7, TP8, TP9, TP10, TP11, TP12, TP13, TP14, TP15, TP16, TP17: TOUCHPADA
TP18, TP19, TP20, TP21, TP22, TP23: TOUCHPADB
U1: RASPBERRY_PICOSMD-TH; PICO-PKG

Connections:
3V3(OUT): U1.36 (3V3(OUT)), U1.P$36 (3V3(OUT))
GND: R1.2, R2.2, R3.2, R4.2, R5.2, R6.2, R7.2, R8.2, R9.2, R10.2, R11.2, R12.2, R13.2, R14.2, R15.2, R16.2, R17.2, R18.2, R19.2, R20.2, R21.2, R22.2, R23.2, U1.3 (GND), U1.8 (GND), U1.13 (GND), U1.18 (GND), U1.23 (GND), U1.28 (GND), U1.33 (GND), U1.38 (GND), U1.P$3 (GND), U1.P$8 (GND), U1.P$13 (GND), U1.P$18 (GND), U1.P$23 (GND), U1.P$28 (GND), U1.P$33 (GND), U1.P$38 (GND)
GP0: R1.1, TP1.TP, U1.1 (GP0), U1.P$1 (GP0)
GP1: R2.1, TP2.TP, U1.2 (GP1), U1.P$2 (GP1)
GP2: R3.1, TP3.TP, U1.4 (GP2), U1.P$4 (GP2)
GP3: R4.1, TP4.TP, U1.5 (GP3), U1.P$5 (GP3)
GP4: R5.1, TP5.TP, U1.6 (GP4), U1.P$6 (GP4)
GP5: R6.1, TP6.TP, U1.7 (GP5), U1.P$7 (GP5)
GP6: R7.1, TP7.TP, U1.9 (GP6), U1.P$9 (GP6)
GP7: R8.1, TP8.TP, U1.10 (GP7), U1.P$10 (GP7)
GP8: R9.1, TP9.TP, U1.11 (GP8), U1.P$11 (GP8)
GP9: R10.1, TP10.TP, U1.12 (GP9), U1.P$12 (GP9)
GP10: R11.1, TP11.TP, U1.14 (GP10), U1.P$14 (GP10)
GP11: R12.1, TP12.TP, U1.15 (GP11), U1.P$15 (GP11)
GP12: R13.1, TP13.TP, U1.16 (GP12), U1.P$16 (GP12)
GP13: R14.1, TP14.TP, U1.17 (GP13), U1.P$17 (GP13)
GP14: R15.1, TP15.TP, U1.19 (GP14), U1.P$19 (GP14)
GP15: R16.1, TP16.TP, U1.20 (GP15), U1.P$20 (GP15)
GP16: R17.1, TP17.TP, U1.21 (GP16), U1.P$21 (GP16)
GP17: R18.1, TP18.TP, U1.22 (GP17), U1.P$22 (GP17)
GP18: R19.1, TP19.TP, U1.24 (GP18), U1.P$24 (GP18)
GP19: R20.1, TP20.TP, U1.25 (GP19), U1.P$25 (GP19)
GP20: R21.1, TP21.TP, U1.26 (GP20), U1.P$26 (GP20)
GP21: R22.1, TP22.TP, U1.27 (GP21), U1.P$27 (GP21)
GP22: R23.1, TP23.TP, U1.29 (GP22), U1.P$29 (GP22)
GP26: U1.31 (GP26), U1.P$31 (GP26)
GP27: U1.32 (GP27), U1.P$32 (GP27)
GP28: U1.34 (GP28), U1.P$34 (GP28)
SWGND: U1.42 (SWGND), U1.P$42 (SWGND)
VBUS: U1.40 (VBUS), U1.P$40 (VBUS)
VSYS: U1.39 (VSYS), U1.P$39 (VSYS)

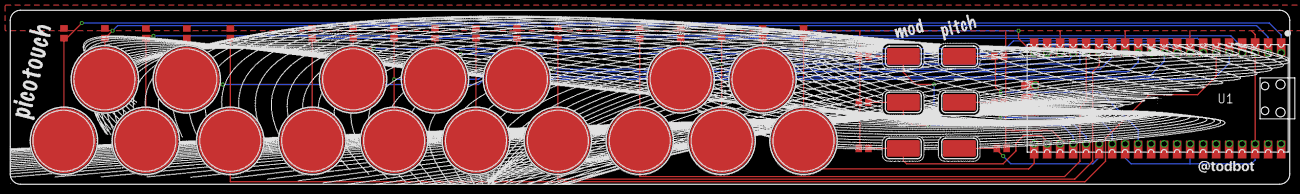
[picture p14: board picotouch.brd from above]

Board: 2 copper layers, 250.0 x 34.0 mm, 48 parts (0 on the bottom side), 31 nets.

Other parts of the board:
U$1: PICOTOUCH_TOPSILK

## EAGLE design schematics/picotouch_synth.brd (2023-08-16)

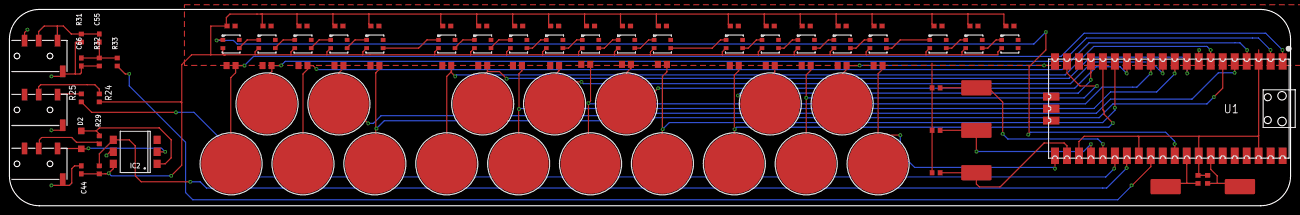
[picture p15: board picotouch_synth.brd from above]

Board: 2 copper layers, 271.6 x 41.6 mm, 100 parts (0 on the bottom side), 54 nets.

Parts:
C1, C2, C3, C4, C5, C6, C7, C8, C9, C10, C11, C12, C13, C14, C15, C16, C17, C18, C19, C20, C44, C66: 100n; C0603
C55: 47uF; C0603
D2: 1N4148; SOD123
IC2: H11L1MS; DIL6-SMD
J1, J3, J4: AUDIO-JACK-TRRS; PJ-320D_SPARKFUN
LED1, LED2, LED3, LED4, LED5, LED6, LED7, LED8, LED9, LED10, LED11, LED12, LED13, LED14, LED15, LED16, LED17, LED18, LED19, LED20: WS2812B3535; LED3535
R1, R2, R3, R4, R5, R6, R7, R8, R9, R10, R11, R12, R13, R14, R15, R16, R17: R0805
R18, R19, R20, R21, R22: R0603
R24: 33; R0603
R25: 10; R0603
R29, R33: 220; R0603
R30: 4.70k; R0603
R31: 1.8k; R0603
R32: 100; R0603
TP1, TP2, TP3, TP4, TP5, TP6, TP7, TP8, TP9, TP10, TP11, TP12, TP13, TP14, TP15, TP16, TP17: TOUCHPADA
TP18, TP19, TP20, TP21, TP22: TOUCHPADB
U1: RASPBERRY_PICOSMD; PICO-PKG-SMD

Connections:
+3V3: C1.1, C2.1, C3.1, C4.1, C5.1, C6.1, C7.1, C8.1, C9.1, C10.1, C11.1, C12.1, C13.1, C14.1, C15.1, C16.1, C17.1, C18.1, C19.1, C20.1, C44.1, IC2.6, LED1.2, LED2.2, LED3.2, LED4.2, LED5.2, LED6.2, LED7.2, LED8.2, LED9.2, LED10.2, LED11.2, LED12.2, LED13.2, LED14.2, LED15.2, LED16.2, LED17.2, LED18.2, LED19.2, LED20.2, R24.1, R30.1
AUDIO_OUT: C55.2, J4.RING1, J4.TIP, R31.1
GND: C1.2, C2.2, C3.2, C4.2, C5.2, C6.2, C7.2, C8.2, C9.2, C10.2, C11.2, C12.2, C13.2, C14.2, C15.2, C16.2, C17.2, C18.2, C19.2, C20.2, C44.2, C66.2, IC2.5, J1.EARTH, J3.EARTH, J4.EARTH, J4.RING2, LED1.4, LED2.4, LED3.4, LED4.4, LED5.4, LED6.4, LED7.4, LED8.4, LED9.4, LED10.4, LED11.4, LED12.4, LED13.4, LED14.4, LED15.4, LED16.4, LED17.4, LED18.4, LED19.4, LED20.4, R1.2, R2.2, R3.2, R4.2, R5.2, R6.2, R7.2, R8.2, R9.2, R10.2, R11.2, R12.2, R13.2, R14.2, R15.2, R16.2, R17.2, R18.2, R19.2, R20.2, R21.2, R22.2, R31.2, R32.1, U1.P$3, U1.P$8, U1.P$13, U1.P$18, U1.P$23, U1.P$28, U1.P$33, U1.P$38
GP0: R1.1, TP1.TP, U1.P$1
GP1: R2.1, TP2.TP, U1.P$2
GP2: R3.1, TP3.TP, U1.P$4
GP3: R4.1, TP4.TP, U1.P$5
GP4: R5.1, TP5.TP, U1.P$6
GP5: R6.1, TP6.TP, U1.P$7
GP6: R7.1, TP7.TP, U1.P$9
GP7: R8.1, TP8.TP, U1.P$10
GP8: R9.1, TP9.TP, U1.P$11
GP9: R10.1, TP10.TP, U1.P$12
GP10: R11.1, TP11.TP, U1.P$14
GP11: R12.1, TP12.TP, U1.P$15
GP12: R13.1, TP13.TP, U1.P$16
GP13: R14.1, TP14.TP, U1.P$17
GP14: R15.1, TP15.TP, U1.P$19
GP15: R16.1, TP16.TP, U1.P$20
GP16: R17.1, TP17.TP, U1.P$21
GP17: R18.1, TP18.TP, U1.P$22
GP18: R19.1, TP19.TP, U1.P$24
GP19: R20.1, TP20.TP, U1.P$25
GP27: R21.1, TP21.TP, U1.P$32
GP28: R22.1, TP22.TP, U1.P$34
MIDI_IN: IC2.4, R30.2, U1.P$27
MIDI_OUT: R25.1, U1.P$26
unnamed: D2.C, IC2.1, R29.1
unnamed: J1.TIP, R25.2
unnamed: D2.A, IC2.2, J3.TIP
unnamed: J3.RING1, R29.2
unnamed: C55.1, C66.1, R32.2, R33.1
unnamed: J1.RING1, R24.2
unnamed: LED1.3, LED2.1
unnamed: LED4.3, LED5.1
unnamed: LED5.3, LED6.1
unnamed: LED6.3, LED7.1
unnamed: LED7.3, LED8.1
unnamed: LED2.3, LED3.1
unnamed: LED3.3, LED4.1
unnamed: LED9.3, LED10.1
unnamed: LED12.3, LED13.1
unnamed: LED13.3, LED14.1
unnamed: LED14.3, LED15.1
unnamed: LED15.3, LED16.1
unnamed: LED10.3, LED11.1
unnamed: LED11.3, LED12.1
unnamed: LED8.3, LED9.1
unnamed: LED16.3, LED17.1
unnamed: LED18.3, LED19.1
unnamed: LED19.3, LED20.1
unnamed: LED17.3, LED18.1
NEOPIXEL: LED1.1, U1.P$31
PWM_AUDIO: R33.2, U1.P$29

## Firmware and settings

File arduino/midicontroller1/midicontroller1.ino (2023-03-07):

/**
   midicontroller1.ino -- Arduino version of picotouch MIDI controller
   2 Aug 2022 - @todbot / Tod Kurt

   Libraries needed:
   - "arduino-pico" core for Pico - https://arduino-pico.readthedocs.io/en/latest/
   - Adafruit_TinyUSB - also select in IDE "Tools / USB Stack: Adafruit TinyUSB"

 **/


#include <Adafruit_TinyUSB.h>
#include <MIDI.h>

#include "TouchyTouch.h"


int midi_base_note = 48; // 48 = C3
int midi_velocity = 64;  // midpoint
int midi_channel = 1;    // 1-16
int midi_cc_num = 1;     // 1 = standard modwheel

const int touch_threshold_adjust = 300;

const int touch_pins[] = {0, 1, 2, 3, 4, 5, 6, 7, 8, 9, 10, 11, 12, 13, 14, 15, 16, 17, 18, 19, 20, 21, 22};
const int touch_count = sizeof(touch_pins) / sizeof(int);

const int pitch_up_index = 22;
const int pitch_down_index = 21;
const int mod_up_index = 19;
const int mod_down_index = 18;
const int oct_up_index = 20;
const int oct_down_index = 17;

Adafruit_USBD_MIDI usb_midi;
MIDI_CREATE_INSTANCE(Adafruit_USBD_MIDI, usb_midi, MIDIusb);

TouchyTouch touches[touch_count];

void setup() {
  Serial.begin(115200);
  Serial.println("picotouch midicontroller1");

  pinMode(PIN_LED, OUTPUT);

  MIDIusb.begin(MIDI_CHANNEL_OMNI);   // Initiate MIDI communications, listen to all channels
  MIDIusb.turnThruOff();    // turn off echo

  // delay to let power stabilize a little so touch calibration read goes okay
  delay(1000);

  // Touch buttons
  for (int i = 0; i < touch_count; i++) {
    touches[i].begin( touch_pins[i] );
    touches[i].threshold += touch_threshold_adjust; // make a bit more noise-proof
  }
}

int pitchbend_val = 0; // midpoint
int modwheel_val = 0;

void loop() {
  // key handling
  for ( int i = 0; i < touch_count; i++) {
    touches[i].update();

    if ( touches[i].rose() ) {
      Serial.printf("press       %d %d %d\n", i, touches[i].raw_value, touches[i].threshold);
      digitalWrite(PIN_LED, HIGH);

      if ( i == oct_up_index ) {
        Serial.println("oct up!");
        midi_base_note = min( midi_base_note + 12, 108);
      }
      else if ( i == oct_down_index ) {
        Serial.println("oct down!");
        midi_base_note = max( midi_base_note - 12, 0);
      }
      else if ( i == pitch_up_index) {
        Serial.println("pitch up!");
        pitchbend_val = 4096; // full up
        MIDIusb.sendPitchBend(pitchbend_val, midi_channel);
      }
      else if ( i == pitch_down_index ) {
        Serial.println("pitch down!");
        pitchbend_val = - 4096; // full down
        MIDIusb.sendPitchBend(pitchbend_val, midi_channel);
      }
      else if ( i == mod_up_index ) {
        Serial.println("mod up!");
        modwheel_val = 127;
        MIDIusb.sendControlChange(midi_cc_num, modwheel_val, midi_channel);
      }
      else if ( i == mod_down_index ) {
        Serial.println("mod down!");
        modwheel_val = 0;
        MIDIusb.sendControlChange(midi_cc_num, modwheel_val, midi_channel);
      }
      else {
        MIDIusb.sendPitchBend(0, midi_channel);
        MIDIusb.sendNoteOn(midi_base_note + i, midi_velocity, midi_channel);
      }
    }

    if ( touches[i].fell() ) {
      Serial.printf("    release %d %d %d\n", i, touches[i].raw_value, touches[i].threshold);
      digitalWrite(PIN_LED, LOW);
      if ( i == oct_up_index ) {
      }
      else if ( i == oct_down_index ) {
      }
      else if ( i == pitch_up_index) {
      }
      else if ( i == pitch_down_index ) {
      }
      else if ( i == mod_up_index ) {
      }
      else if ( i == mod_down_index ) {
      }
      else {  // notes!
        MIDIusb.sendNoteOff(midi_base_note + i, midi_velocity, midi_channel);
      }
    }
  }

}

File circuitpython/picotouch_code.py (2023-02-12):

#
# picotouch code.py -- Tiny capsense MIDI controller using Raspberry Pi Pico
# 2022 - @todbot / Tod Kurt - github.com/todbot/picotouch
#
# To use:
#
# 1. Install needed libraries:
#   circup install adafruit_midi adafruit_debouncer
# 2. Copy over this file as code.py:
#   cp picotouch_code.py /Volumes/CIRCUITPY/code.py
#
# on Pico / RP2040, need 1M pull-down on each input
#

import time
import board
from digitalio import DigitalInOut, Pull, Direction
import touchio
import usb_midi
import adafruit_midi
from adafruit_midi.note_off import NoteOff
from adafruit_midi.note_on  import NoteOn
from adafruit_midi.pitch_bend  import PitchBend
from adafruit_midi.control_change  import ControlChange
from adafruit_debouncer import Debouncer, Button

debug = True

octave = 4

midi_velocity = 64  # midpoint
midi_channel = 0  # 0-15
midi_cc_num = 1   # standard modwheel

touch_threshold_adjust = 300

midi = adafruit_midi.MIDI(midi_out=usb_midi.ports[1])

touch_pins = (
    board.GP0, board.GP1, board.GP2, board.GP3, board.GP4, board.GP5,
    board.GP6, board.GP7, board.GP8, board.GP9, board.GP10, board.GP11,
    board.GP12, board.GP13, board.GP14, board.GP15, board.GP16, board.GP17,
    board.GP18, board.GP19, board.GP20, board.GP21,
    board.GP22,
)

led = DigitalInOut(board.LED) # defaults to input
led.direction = Direction.OUTPUT

# special keys that aren't notes
pitch_up_key = 22
pitch_dn_key = 21

mod_up_key = 19
mod_mid_key = 18

oct_up_key = 20
oct_dn_key = 17

touch_ins = []  # for debug
touch_pads = []
for pin in touch_pins:
    touchin = touchio.TouchIn(pin)
    touchin.threshold += touch_threshold_adjust
    touch_pads.append( Button(touchin, value_when_pressed=True))
    touch_ins.append(touchin)  # for debug
num_touch_pads = len(touch_pads)

print("\n----------")
print("picotouch hello")

while True:
    for i in range(num_touch_pads):
        touch = touch_pads[i]
        touch.update()
        if touch.rose:
            led.value = True
            if debug: print('key press   %2d' % i, "touch:",touch_ins[i].raw_value, touch_ins[i].threshold)
            if i == pitch_up_key:
                print('pitch up!')
                pitchbend_val = 8192 + 4096
                midi.send( PitchBend(pitchbend_val), channel=midi_channel)
            elif i == pitch_dn_key:
                print('pitch middle!')
                pitchbend_val = 8192 - 4096
                midi.send( PitchBend(pitchbend_val), channel=midi_channel)
            elif i == mod_up_key:
                print('mod up!')
                modwheel_val = 127
                midi.send( ControlChange(midi_cc_num, modwheel_val), channel=midi_channel)
            elif i == mod_mid_key:
                print('mod middle!')
                modwheel_val = 64
                midi.send( ControlChange(midi_cc_num, modwheel_val), channel=midi_channel)
            elif i == oct_up_key:
                if octave < 9: octave = octave + 1
                print('oct up!', octave)
            elif i == oct_dn_key:
                if octave > 0: octave = octave - 1
                print('oct down!', octave)
            else:
                midi.send( PitchBend(8192) , channel=midi_channel)
                midi.send( NoteOn((12*octave) + i, midi_velocity), channel=midi_channel )

        if touch.fell:
            led.value = False
            if debug: print("key release %2d" % i, "touch:",touch_ins[i].raw_value, touch_ins[i].threshold)
            if i == pitch_up_key:
                pitchbend_val = 8192  # reset to midpoint
                midi.send( PitchBend(pitchbend_val), channel=midi_channel)
            elif i == pitch_dn_key:
                pitchbend_val = 8192  # reset to midpoint
                midi.send( PitchBend(pitchbend_val), channel=midi_channel)
            elif i == mod_up_key:
                modwheel_val = 0  # reset to normal
                midi.send( ControlChange(midi_cc_num, modwheel_val), channel=midi_channel)
            elif i == mod_mid_key:
                modwheel_val = 0
                midi.send( ControlChange(midi_cc_num, modwheel_val), channel=midi_channel)
            elif i == oct_up_key:
                pass
            elif i == oct_dn_key:
                pass
            else:
                midi.send( NoteOff((12*octave) + i, midi_velocity), channel=midi_channel )

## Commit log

2021-04-14 submitted to pcbway
    [picotouch.brd, picotouch.sch]
2021-04-20 aha fix touch sensitivity of fingers hitting traces
    [picotouch_code.py]
2021-04-21 added enclosure design; added oshpark link
    [picotouch_enclosure.f3z, picotouch_enclosure.stl, picotouch_enclosure_top.stl]
2021-04-22 first (bad) cut at ch/pitch/mod buttons
2022-11-19 maybe picotouchsynth
    [picotouchsynth.brd, picotouchsynth.sch]
2022-11-19 more picotouchsynth
    [picotouchsynth.brd, picotouchsynth.sch]
2022-11-23 picotouchsynth version sent to fab
    [picotouchsynth.sch]
2023-01-17 modbuttons circuitpython
2023-01-17 add simple arduino demo
2023-01-19 sent picotouch_smd to fab
    [picotouch_smd.sch, picotouchsynth.sch]
2023-02-02 picotouch_code.py matches new silkscreen
2023-02-03 add arduino midicontroller1 example, it mostly works.
2023-02-08 soldering video
2023-02-12 update circuitpython code
2023-02-12 woops need that for LED blinkin
2023-02-15 grid idea
    [picotouch_grid.brd, picotouch_grid.sch]
2023-02-15 more grid idea
    [picotouch_grid.brd, picotouch_grid.sch]
2023-02-15 grid idea has cutout now
    [picotouch_grid.brd, picotouch_grid.sch]
2023-02-16 reorg grid idea
    [picotouch_grid.brd, picotouch_grid.sch]
2023-02-18 do note off correctly for held notes and octave change. fixes #2
    [code.py]
2023-03-01 added gpio pins 16,17,18,19 as smd touchpads for hacking
    [picotouch_grid.brd, picotouch_grid.sch]
2023-03-02 added test points
    [picotouch_grid.brd, picotouch_grid.sch]
2023-03-07 more experiments with touchpads
    [picotouch_grid.brd]
2023-03-07 arduino: better touch library! uses higher drive strength to charge pads
2023-03-08 arduino: clean up touchytouch capsense library
2023-04-07 added but pico dual smd footprint is too wide
    [picotouch_grid_mpr.brd, picotouch_grid_mpr.sch]
2023-06-26 make more clear that tindie picotouch has resistors
2023-08-16 move confusing research code to research dir
    [picotouch_grid_mpr.brd, picotouch_grid_mpr.sch]
2023-08-16 first picotouch_synth, (actually sixth but first of this style)
    [picotouch_synth.brd, picotouch_synth.sch]
2023-08-16 first cut at picotouch_synth pcb art
    [picotouch_synth.sch]
2023-08-16 adding slidercase from printables
    [picotouch_slidercase v27.f3z, picotouch_slidercase_bottom.stl, picotouch_slidercase_picocap.stl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]
2023-08-16 moved picotouch_synth to its own repo
    [picotouch_synth.sch]
2024-03-22 circuitpython hwtest: fix up wow super old bug
    [code.py]

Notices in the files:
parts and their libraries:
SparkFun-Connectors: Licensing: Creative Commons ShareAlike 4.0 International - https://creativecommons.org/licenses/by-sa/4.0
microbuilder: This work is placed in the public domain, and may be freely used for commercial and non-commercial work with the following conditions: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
